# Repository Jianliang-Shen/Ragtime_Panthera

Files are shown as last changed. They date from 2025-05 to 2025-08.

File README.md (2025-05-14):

# Ragtime_Panthera
A set of six axis gripper robotic arm based on DM actuator.

## Acknowledgements

This project was collaboratively developed by **wEch1ng (芝士榴莲肥牛)** and myself.  

The initial concept for the Panthera project was proposed by wEch1ng. During its development, I provided **technical guidance**, **environment setup**, **partial sponsorship**, and was heavily involved in **debugging and hardware verification**, contributing to roughly 'a little bit' of the overall workload.

Both of us built our own arm and worked through some iterations. In fact, the debugging phase was intense—we each sustained minor injuries 🤕 while assembling and tuning the robotic arm, so we sincerely remind everyone: **please prioritize safety** when working with mechanical systems.

The **core structure design**, **initial implementation**, and **main codebase** were led and mostly completed by wEch1ng. My role focused more on **repeated system testing**, **tutorial creation**, and **collaborative validation**. While it was a joint project in many respects, I believe **the primary credit still goes to wEch1ng**, who generously contributed this full-featured robotic arm and gripper system to the open-source community.

If you'd like to show appreciation or offer support, please feel free to contact him directly at: **3575868884@qq.com**

> 🙌 Please direct your thanks, recognition, and any donations to **wEch1ng**, the key driving force behind Panthera.

## Tutorials

Updated Python Tutorial DEMO

Working on Installation Guide (ing)



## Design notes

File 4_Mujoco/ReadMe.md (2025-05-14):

# MuJoCo-Panthera Environment Setup

This repository provides a working setup for MuJoCo-based robotic simulation integrated with Kinova arm kinematics. It includes a set of dependencies optimized for Python 3.10 and visualization/control tools.

## Environment Setup

We recommend setting up a clean conda environment.

```bash
# Step 1: Create and activate the environment
conda create --name MuJoCo-Panthera python=3.10
conda activate MuJoCo-Panthera

# Step 2: Upgrade core tools
python -m pip install --upgrade pip setuptools wheel
```

## Dependency Installation
Install the following required packages (for now):
```bash
# Install Pinocchio from conda-forge
conda install pinocchio -c conda-forge

# Install other Python packages (note: numpy is pinned to <2.0.0 due to compatibility)
pip install mujoco dearpygui scipy numpy<2.0.0 pandas matplotlib scikit-learn PyQt6 pyserial -i https://pypi.tuna.tsinghua.edu.cn/simple
```

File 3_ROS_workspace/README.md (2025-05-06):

## ⚠️ Update Notice

> **Starting from commit**: `Together Fixed Axis-6 bug for now.`  
> This marks the beginning of the **latest stable version** of the code.

Previous versions uploaded to this repository were outdated and may contain bugs related to **Axis 6**, such as unexpected behavior during joint control or motion execution.

This commit introduces a revised and tested implementation that addresses these issues.  
We **strongly recommend** starting from this version to ensure proper functionality and stability.

If you were using an earlier version, please consider backing up your changes and switching to the updated codebase.

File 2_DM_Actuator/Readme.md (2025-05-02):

# Motor Documentation and Software

This project uses the following motors:

- **DM4310**
- **DM4340**
- **DM3510**

## Provided Resources

We have included **user manuals** and **PC-side control software** for the above motors. These resources are sourced from the official Gitee repository and are provided here for convenience.

- Manuals and software were downloaded from: [https://gitee.com/kit-miao](https://gitee.com/kit-miao)

If you require more detailed information, updates, or firmware, please visit the official repository directly.

---

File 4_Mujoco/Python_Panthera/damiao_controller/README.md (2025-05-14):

# 达妙Python库

该库支持MAC,Linux,Windows三个平台

**欢迎加入QQ群：677900232 进行达妙电机技术交流。欢迎进入达妙店铺进行点击选购**[首页-达妙智能控制企业店-淘宝网 (taobao.com)](https://shop290016675.taobao.com/?spm=pc_detail.29232929/evo365560b447259.shop_block.dshopinfo.59f47dd6w4Z4dX)

### 1.引用达妙库

默认文件夹下有两个文件DM_CAN.py为所在的电机库，使用的时候

```python
from DM_CAN import *	
```
在此工程中需要使用
```python
from Python_Panthera.damiao_controller.DM_CAN import *
```

电机库相关依赖是serial , numpy 这几个库，记得安装相关依赖。**具体的requirements在目录下面的requirements.txt，这个版本是我目前测试的版本，比这些版本低理论上应该也没啥问题。**

### 2.定义控制对象

定义电机对象，有几个电机就定义几个。重要的事情：不要把masterid设为0x00

```python
Motor1=Motor(DM_Motor_Type.DM4310,0x01,0x11)
Motor2=Motor(DM_Motor_Type.DM4310,0x02,0x12)
Motor3=Motor(DM_Motor_Type.DM4310,0x03,0x13)
```

第一个参数为电机类型，第二个是SlaveID即电机的CANID（电机的ID）,第三个参数是MasterID是主机ID，建议MasterID设置的都不一样，比SlaveID整体高一个。

例如Motor1的SlaveID是0x01，MasterID是0x11.这样是最好。

**MasterID和SlaveID需要在达妙上位机进行设置！！如果出现问题请先检查MasterID是否不和SlaveID冲突，并且不为0x00**

**MasterID不要设置为0x00**

**MasterID不要设置为0x00**

**MasterID不要设置为0x00**

python使用serial串口，波特率是921600，串口进行选择。demo是windows所以是'COM8'

```python
serial_device = serial.Serial('COM8', 921600, timeout=0.5)
```

初始化电机控制对象。传入参数是定义的串口对象

```python
MotorControl1=MotorControl(serial_device)
```

### 3.电机状态

#### 3.1 添加电机

添加电机是addMotor。

```python
MotorControl1.addMotor(Motor1)
MotorControl1.addMotor(Motor2)
MotorControl1.addMotor(Motor3)
```

#### 3.2使能电机

**建议：如果要修改电机参数。建议使能放在最后**

```python
MotorControl1.enable(Motor1)
MotorControl1.enable(Motor2)
MotorControl1.enable(Motor3)
```

此代码为兼容旧固件，关于旧版本电机固件，使能对应不同模式需要加上使能的模式（即需要使能电机对应的模式，并不能修改电机此时的模式）**注意需要使能电机此时对应的模式，并不能修改电机内部的模式**

```python
MotorControl1.enable_old(Motor1,Control_Type.MIT)
MotorControl1.enable_old(Motor2,Control_Type.POS_VEL)
MotorControl1.enable_old(Motor3,Control_Type.VEL)
```

#### 3.3设置电机零点

将电机在失能状态下摆到需要设置为0点的位置，然后运行下面两行，电机将会将当前位置作为电机0点。

```python
MotorControl1.set_zero_position(Motor3)
MotorControl1.set_zero_position(Motor6)
```

#### 3.4 失能电机

```python
MotorControl1.disable(Motor3)
MotorControl1.disable(Motor6)
```

#### 3.5 电机状态获取

达妙电机默认是需要每发送一帧控制指令才能获得当前电机力矩、位置、速度等信息。如果在没有发送控制指令的过程中想要获得电机此时的状态可以通过以下指令。

```python
MotorControl1.refresh_motor_status(Motor1)
print("Motor1:","POS:",Motor1.getPosition(),"VEL:",Motor1.getVelocity(),"TORQUE:",Motor1.getTorque())
```

通过**refresh_motor_status**这个函数可以获得当前电机的状态，并保存到对应的电机。

### 4.电机控制模式

**推荐在每帧控制完后延迟2ms或者1ms，usb转can默认有缓冲器没有延迟也可使用，但是推荐加上延迟。**

#### 4.1MIT模式

使能电机后可以使用MIT模式控制，推荐用MIT模式控制。

```python
MotorControl1.controlMIT(Motor1, 50, 0.3, 0, 0, 0)
```

#### 4.2位置速度模式

位置速度模式，第一个参数是电机对象，第二个是位置，第三个是转动速度。具体的参数介绍已经写了函数文档，用pycharm等ide就可以看到。

例子如下

```python
q=math.sin(time.time())
MotorControl1.control_Pos_Vel(Motor1,q*10,2)
```

#### 4.3 速度模式

例子如下，第一个是电机对象，第二个是电机速度

```python
q=math.sin(time.time())
MotorControl1.control_Vel(Motor1, q*5)
```

目前达妙的新固件支持切换

#### 4.4力位混合模式

第一个是电机对象，第二个是电机位置，第三个是电机速度范围是0-10000，第四个是电机电流范围为0-10000。具体详细请查看达妙文档

例子如下

```python
MotorControl1.control_pos_force(Motor1, 10, 1000,100)
```

### 5.电机状态读取

电机的各个状态都保存在对应的电机对象中，需要调用可以用如下几个函数。

**请注意！达妙的电机状态是每次发了控制帧或者刷新状态(refresh_motor_status 函数)后才能刷新电机对象的当前各个信息。！！**

**达妙电机是一发一收模式，只有发送指令电机才会返回当前状态，电机才会更新**

```python
vel = Motor1.getVelocity()    #获得电机速度
pos = Motor1.getPosition()    #获得电机位置
tau = Motor1.getTorque()      #获得电机此时输出力矩
```

```maltab
MotorControl1.refresh_motor_status(Motor1)  print("Motor1:","POS:",Motor1.getPosition(),"VEL:",Motor1.getVelocity(),"TORQUE:",Motor1.getTorque())
```

### 6.电机内部参数更改

达妙电机新固件支持使用can进行电机模式修改，以及修改其他参数等操作。要求版本号5013及以上。具体请咨询达妙客服。**请注意所有保存参数、修改参数。请在失能模式下修改！！**

#### 6.1电机控制模式更改

通过下面的函数可以对电机的控制模式进行修改。支持MIT,POS_VEL,VEL,Torque_Pos。四种控制模式在线修改。下面是修改的demo。并且代码会有返回值，如果是True那么说明设置成功了，如果不是也不一定没修改成功hhhh。**请注意这里模式修改只是当前有效，掉电后这个模式还是修改前的**

```python
if MotorControl1.switchControlMode(Motor1,Control_Type.POS_VEL):
    print("switch POS_VEL success")
if MotorControl1.switchControlMode(Motor2,Control_Type.VEL):
    print("switch VEL success")
```

**如果要保持电机控制模式，需要最后保存参数**

#### 6.2保存参数

默认电机修改模式等操作后参数不会保存到flash中，需要使用命令如下进行保存至电机的flash中。这一个例子如下。**请注意这一个代码就把所有修改的都保存到Motor1的flash中，并且请在失能模式下进行修改**，该函数内部有自动失能的代码，防止电机在使能模式下无法保存参数。

```python
MotorControl1.save_motor_param(Motor1)
```

#### 6.3 读取内部寄存器参数

内部寄存器有很多参数都是可以通过can线读取，具体参数列表请看达妙的手册。其中可以读的参数都已经在DM_variable这个枚举类里面了。可以通过read_motor_param进行读取

```python
print("PMAX:",MotorControl1.read_motor_param(Motor1,DM_variable.PMAX))
print("MST_ID:",MotorControl1.read_motor_param(Motor1,DM_variable.MST_ID))
print("VMAX:",MotorControl1.read_motor_param(Motor1,DM_variable.VMAX))
print("TMAX:",MotorControl1.read_motor_param(Motor1,DM_variable.TMAX))
print("Motor2:")
print("PMAX:",MotorControl1.read_motor_param(Motor2,DM_variable.PMAX))
print("MST_ID:",MotorControl1.read_motor_param(Motor2,DM_variable.MST_ID))
print("VMAX:",MotorControl1.read_motor_param(Motor2,DM_variable.VMAX))
print("TMAX:",MotorControl1.read_motor_param(Motor2,DM_variable.TMAX))
```

并且每次读取参数后，当前的参数也会同时存在对应的电机类里面，通过getParam这个函数进行读取。

```python
print("PMAX",Motor1.getParam(DM_variable.PMAX))
```

#### 6.4改写内部寄存器参数

内部寄存器有一部分是支持修改的，一部分是只读的（无法修改）。通过调用change_motor_param这个函数可以进行寄存器内部值修改。并且也如同上面读寄存器的操作一样，他的寄存器的值也会同步到电机对象的内部值，可以通过Motor1.getParam这个函数进行读取。

**请注意这个修改内部寄存器参数，掉电后会恢复为修改前的，并没有保存**

```python
if MotorControl1.change_motor_param(Motor1,DM_variable.KP_APR,54):
   print("write success")
```

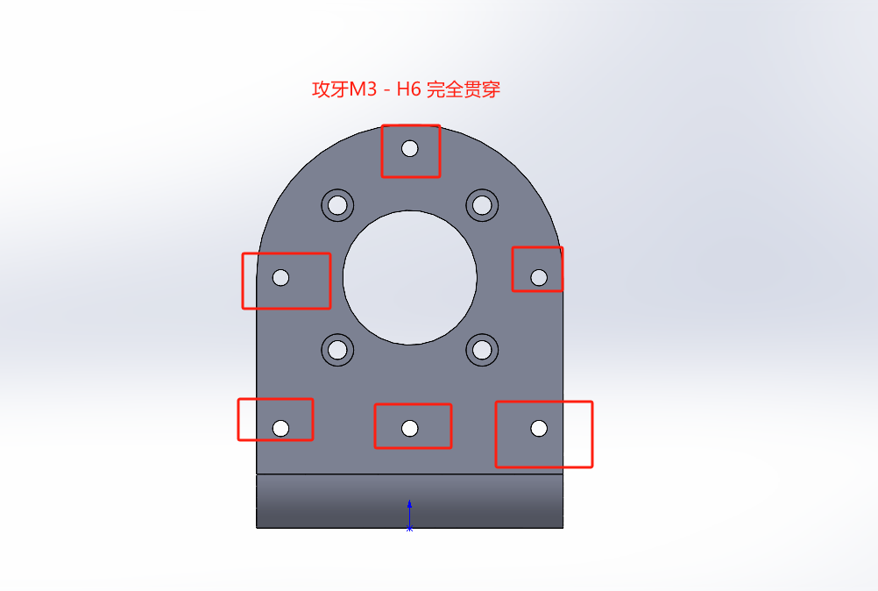
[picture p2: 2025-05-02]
1_3D_Model/2_JLC_metalplate/304_stanless_steel/攻牙图/一二轴.png

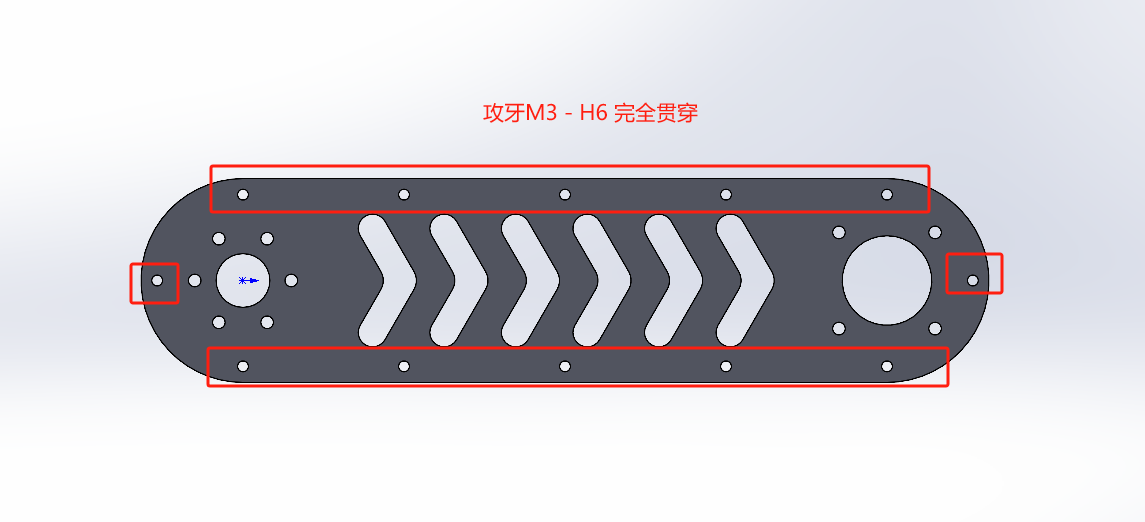
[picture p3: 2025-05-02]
1_3D_Model/2_JLC_metalplate/304_stanless_steel/攻牙图/二三轴.png

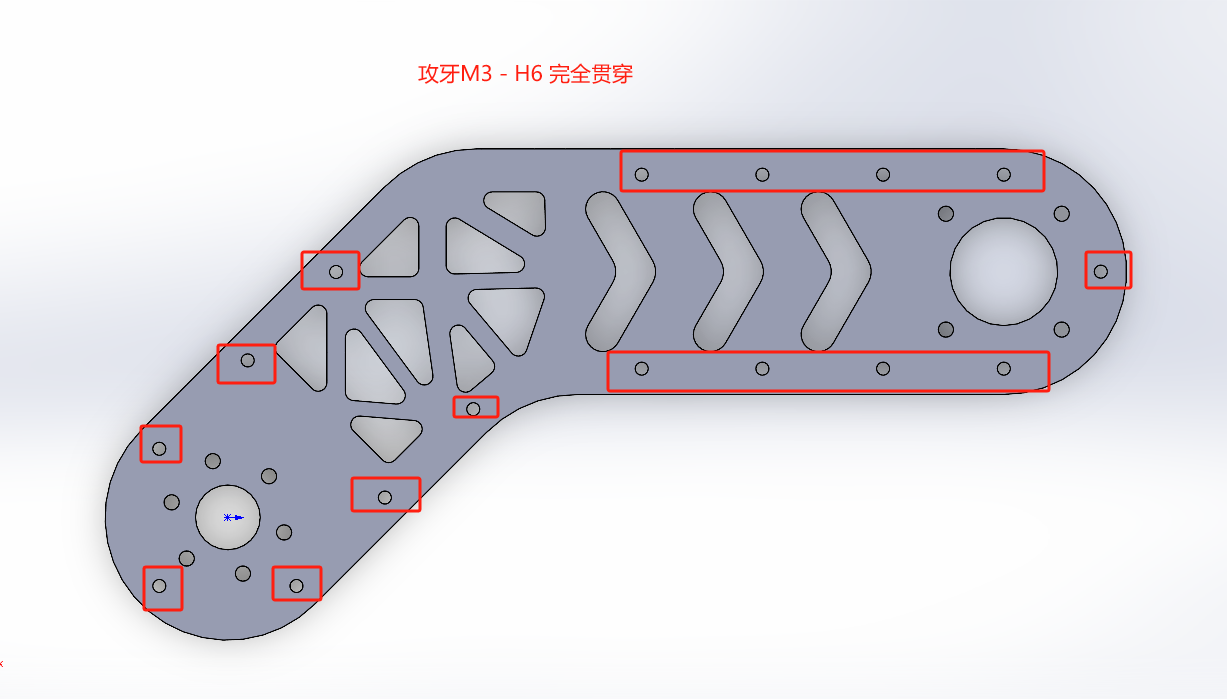
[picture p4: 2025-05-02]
1_3D_Model/2_JLC_metalplate/304_stanless_steel/攻牙图/三四轴.png

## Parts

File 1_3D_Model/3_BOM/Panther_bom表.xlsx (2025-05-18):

序号 | 商品名称 | 数量（件） | 单价 | 总计 | 链接
1 | 若干M3螺丝 | 无 | 无 | 无 | https://detail.tmall.com/item.htm?id=601686286684
2 | 若干M3螺母 | 无 | 无 | 无 | 无
 | 橡胶垫片 M3*6*0.8 (200粒) 白 | 1 | 3.4 | 3.4 | https://detail.tmall.com/item.htm?id=20848580632
3 | 达妙4340电机 | 3 | 799 | 2397 | https://item.taobao.com/item.htm?id=775159686012
4 | 达妙4310新手套装 含USB转CAN 转接板 双端线 | 2 | 669 | 1338 | https://item.taobao.com/item.htm?id=730437945135
5 | 达妙4310电机 | 1 | 599 | 599
6 | 达妙3510电机 | 1 | 199 | 199 | https://item.taobao.com/item.htm?abbucket=4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
7 | XT30（2+2）-F母头升级版 | 14 | 1.85 | 25.9 | https://item.taobao.com/item.htm?id=737472229828
8 | 黑色18AWG | 1 | 14 | 14 | https://item.taobao.com/item.htm?id=654286714565
9 | 红色18AWG | 1 | 14 | 14
10 | 黑色28AWG | 1 | 7 | 7
11 | 红色28AWG | 1 | 7 | 7
12 | 滑块 MGW7C（标准块） | 2 | 18 | 36 | https://item.taobao.com/item.htm?id=848276155434&sku_properties=122276018%3A20213
13 | MGW7导轨100MM（备注做成一根200mm的） | 2 | 10 | 20
14 | 1模凸台20齿 内孔10 | 1 | 4.2 | 4.2 | https://detail.tmall.com/item.htm?id=725141098339
15 | 光学平板300x300x13 | 1 | 275 | 275 | https://item.taobao.com/item.htm?from=cart&id=730306309245&skuId=5230836882690&u_channel=null&umpChannel=null
16 | 嘉立创钣金定制 | 5 | 50 | 250 | 立创下单平台
 | 总价 | 5189.5
 | 3D打印材料
 | 兰博abs+
 | https://detail.tmall.com/item.htm?_u=o2rtso892077&id=645580609321&spm=a1z09.2.0.0.40262e8drWVAiV

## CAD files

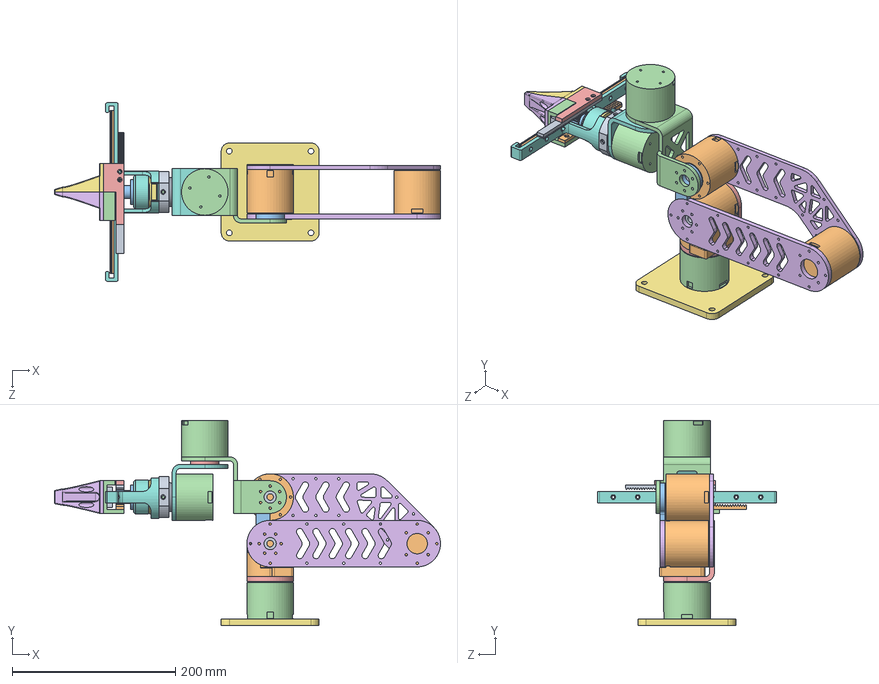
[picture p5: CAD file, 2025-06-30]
1_3D_Model/0_Solidworks2022/无d435/arm/myrobot.SLDASM
472.5 x 251.5 x 218.6 mm
4340电机转子 x 3
4340电机定子 x 3
4310电机转子 x 3
4310电机定子 x 3
一二轴连接件
二三轴连杆
底板
五六轴连接件1
末端法兰
二三轴连杆定位件
四五轴连杆定位件
四五轴连接件
五六轴垫块
三四轴连杆
3510定子
3510转子
MGW9C滑块 x 2
MGW9导轨
转子齿轮连接件
滑块手指连接件
滑块手指连接件2
手指
镜向手指
夹爪外壳
齿条
齿条2
spur gear_gb
外壳内挡块

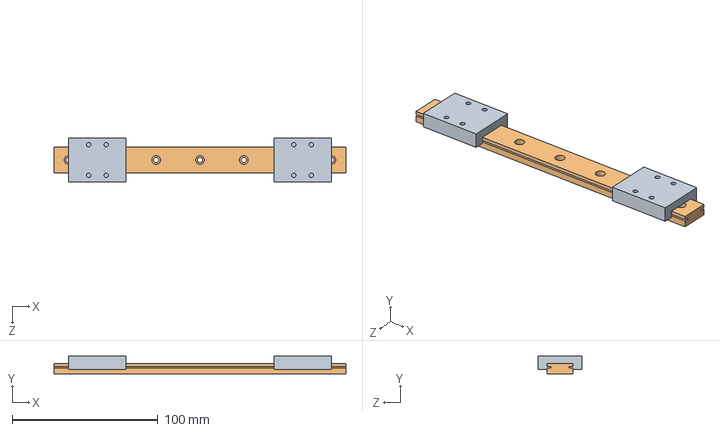
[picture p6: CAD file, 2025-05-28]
1_3D_Model/0_Solidworks2022/无d435/gripper/MGW9导轨滑块模组/MGW9滑轨模组.SLDASM
200.0 x 12.0 x 30.0 mm
MGW9C滑块 x 2
MGW9导轨

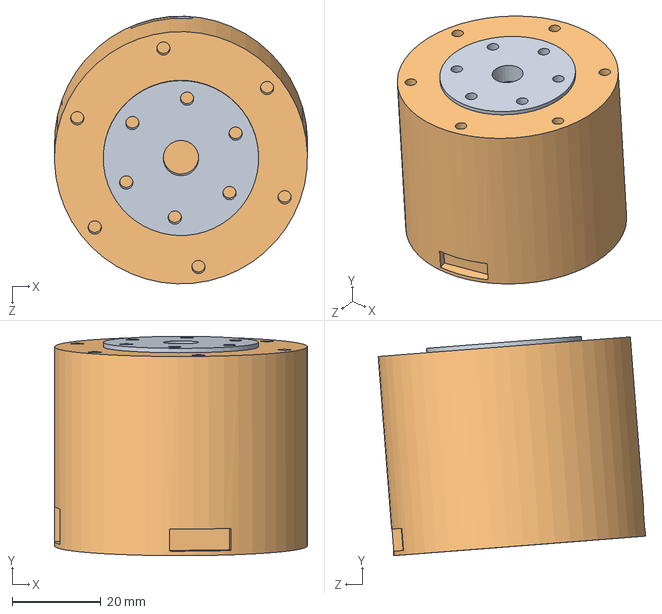
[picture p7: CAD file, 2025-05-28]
1_3D_Model/0_Solidworks2022/有d435/arm/4310电机/4310电机装配体.SLDASM
57.0 x 49.4 x 60.3 mm
4310电机转子
4310电机定子

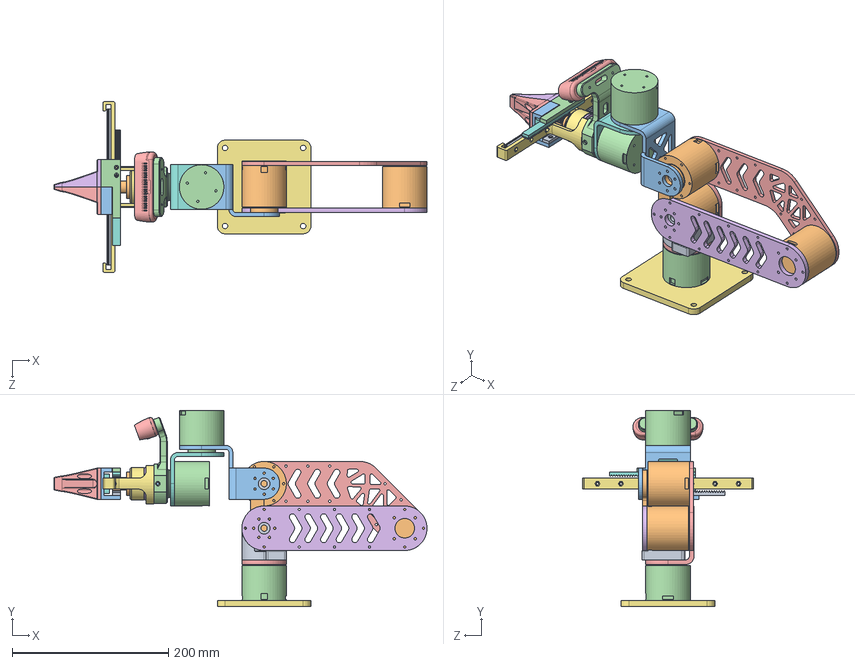
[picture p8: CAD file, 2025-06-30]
1_3D_Model/0_Solidworks2022/有d435/arm/myrobot.SLDASM
477.5 x 251.5 x 218.6 mm
4340电机转子 x 3
4340电机定子 x 3
4310电机转子 x 3
4310电机定子 x 3
一二轴连接件
二三轴连杆
底板
五六轴连接件1
二三轴连杆定位件
四五轴连杆定位件
四五轴连接件
五六轴垫块
三四轴连杆
3510定子
3510转子
MGW9C滑块 x 2
MGW9导轨
转子齿轮连接件
滑块手指连接件
滑块手指连接件2
手指
镜向手指
夹爪外壳
齿条
齿条2
spur gear_gb
外壳内挡块
法兰(带d435)
IntelRealsense_D435_Multibody

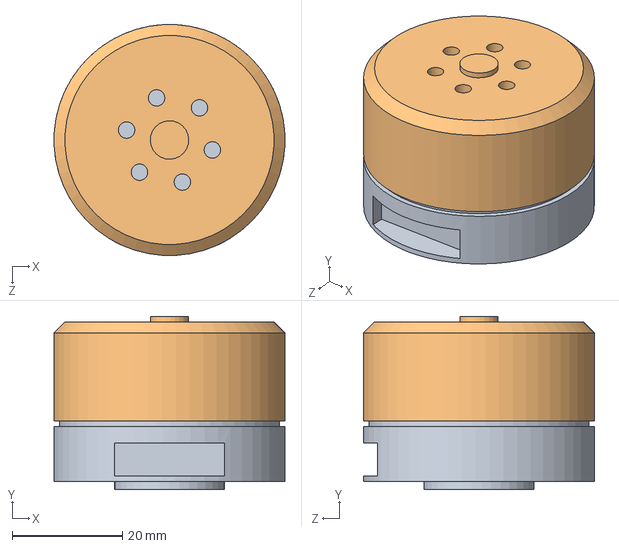
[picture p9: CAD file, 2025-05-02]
1_3D_Model/0_Solidworks2022/无d435/gripper/达妙3510轮毂电机/3510.SLDASM
42.0 x 31.5 x 42.0 mm
3510定子
3510转子

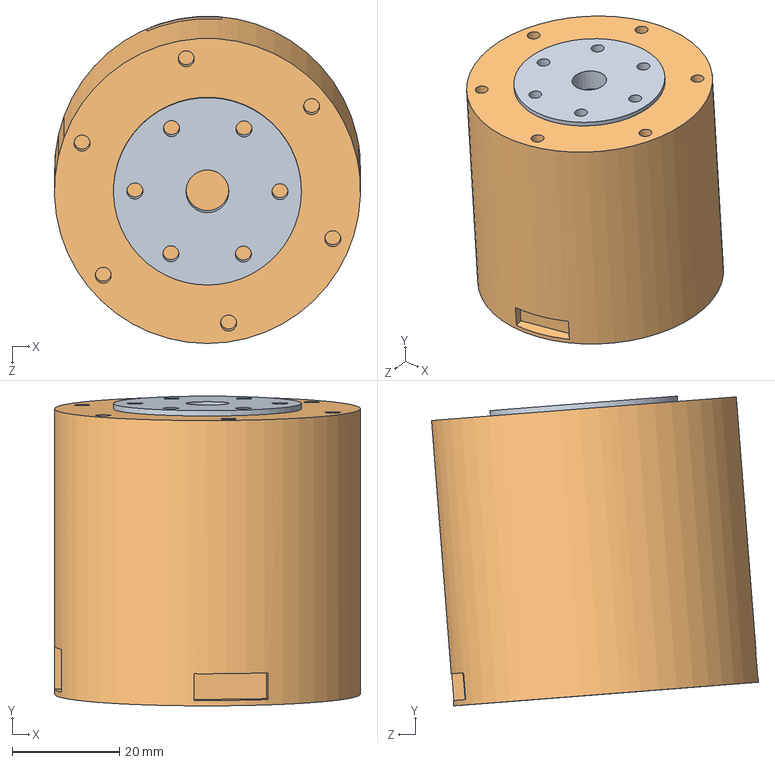
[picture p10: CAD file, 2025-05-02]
1_3D_Model/0_Solidworks2022/有d435/arm/4340电机/4340电机装配体.SLDASM
57.0 x 57.7 x 60.9 mm
4340电机转子
4340电机定子

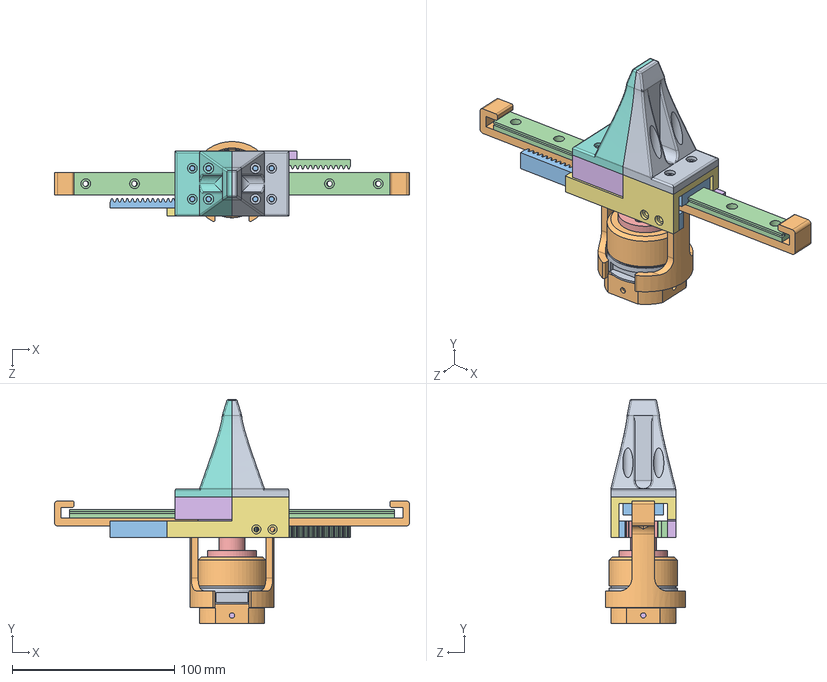
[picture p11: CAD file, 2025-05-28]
1_3D_Model/0_Solidworks2022/无d435/gripper/MyGripper.SLDASM
218.6 x 138.0 x 49.3 mm
3510定子
3510转子
MGW9C滑块 x 2
MGW9导轨
转子齿轮连接件
滑块手指连接件
滑块手指连接件2
手指
镜向手指
夹爪外壳
齿条
齿条2
spur gear_gb
外壳内挡块

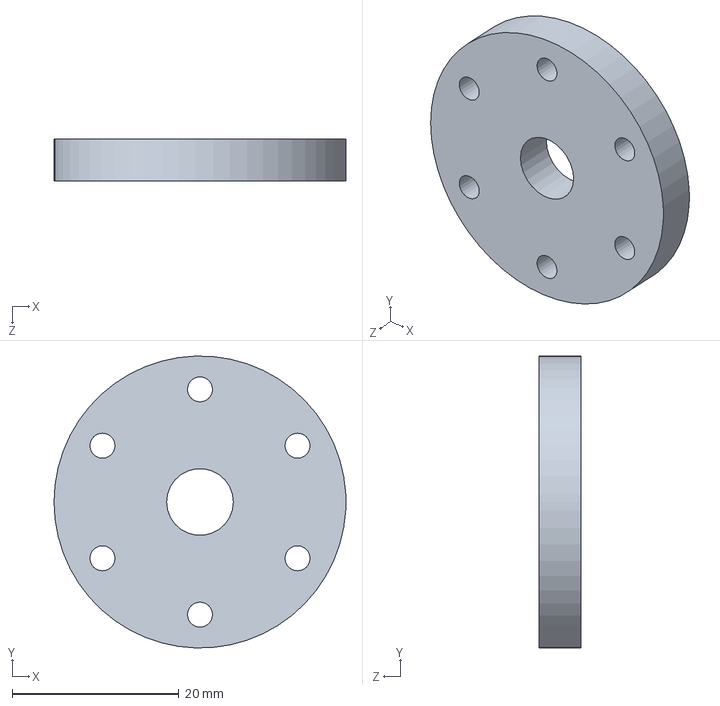
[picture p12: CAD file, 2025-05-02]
1_3D_Model/0_Solidworks2022/无d435/arm/4310电机/4310电机转子.SLDPRT
35.0 x 35.0 x 5.00 mm

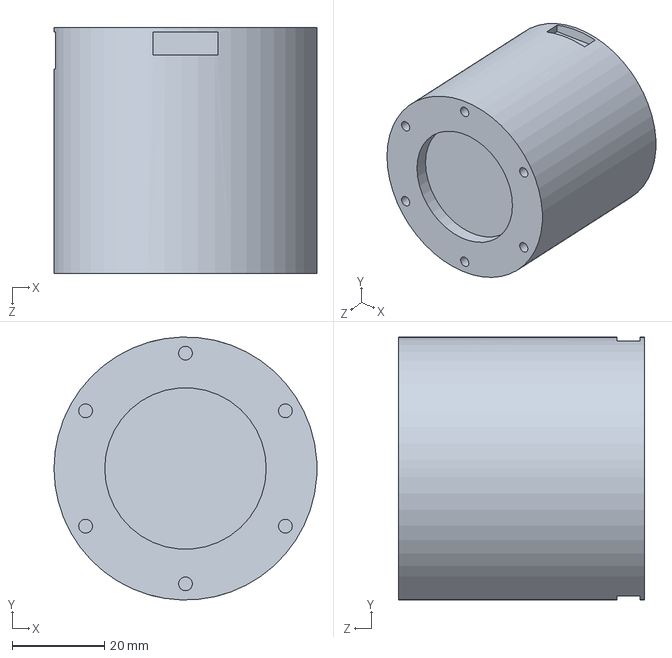
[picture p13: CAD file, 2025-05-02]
1_3D_Model/0_Solidworks2022/无d435/arm/4340电机/4340电机定子.SLDPRT
57.0 x 57.0 x 53.3 mm

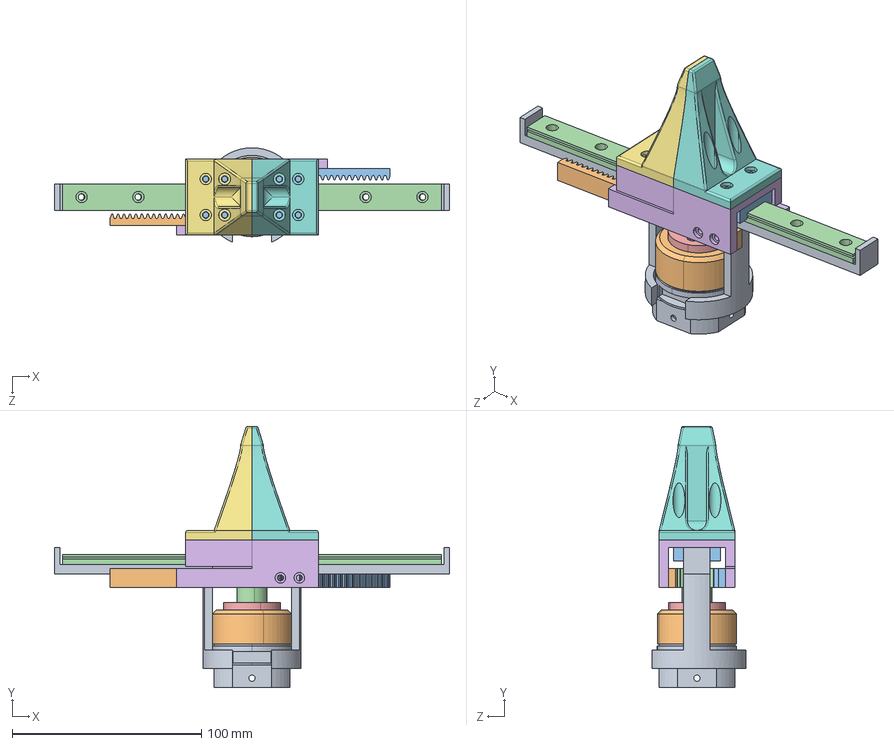
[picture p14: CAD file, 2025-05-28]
1_3D_Model/0_Solidworks2022/无d435/gripper/平行夹爪step/MyGripper.STEP
208.6 x 138.0 x 49.9 mm
3510隅赽
3510蛌赽
MGW9C賑輸 x 2
MGW9絳寢
转子齿轮连接件
滑块手指连接件
滑块手指连接件2
忒硌
镜向手指
ｼﾐﾗｦﾍ篩ﾇ
喘沭
喘沭2
spur gear_gb_GB - Spur gear 1M 20T 20PA 10FW ---S20B16H18L10.0N

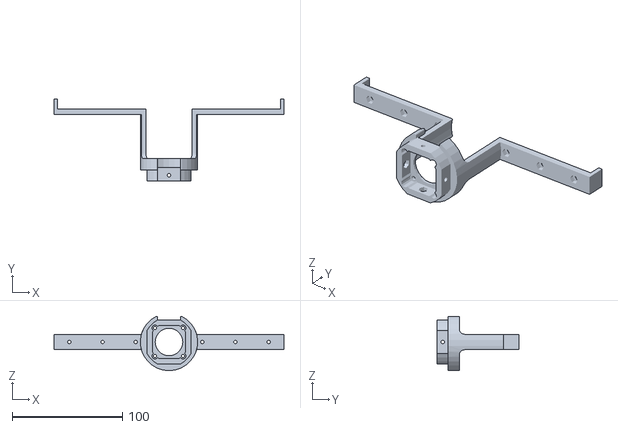
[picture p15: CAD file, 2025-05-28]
1_3D_Model/0_Solidworks2022/无d435/gripper/平行夹爪stl/夹爪外壳.STL
208.6 x 74.0 x 49.3

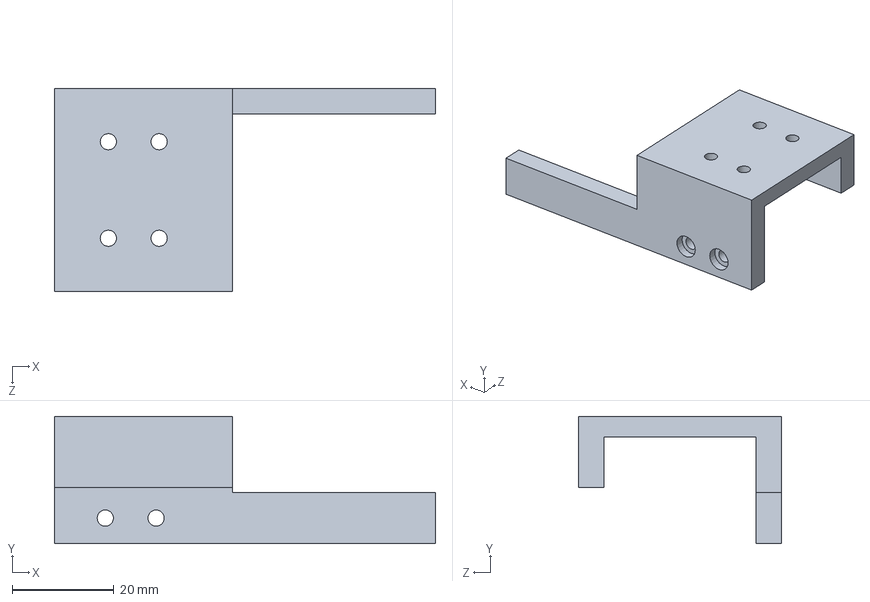
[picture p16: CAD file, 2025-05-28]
1_3D_Model/0_Solidworks2022/无d435/gripper/滑块手指连接件2.SLDPRT
75.0 x 25.0 x 40.0 mm

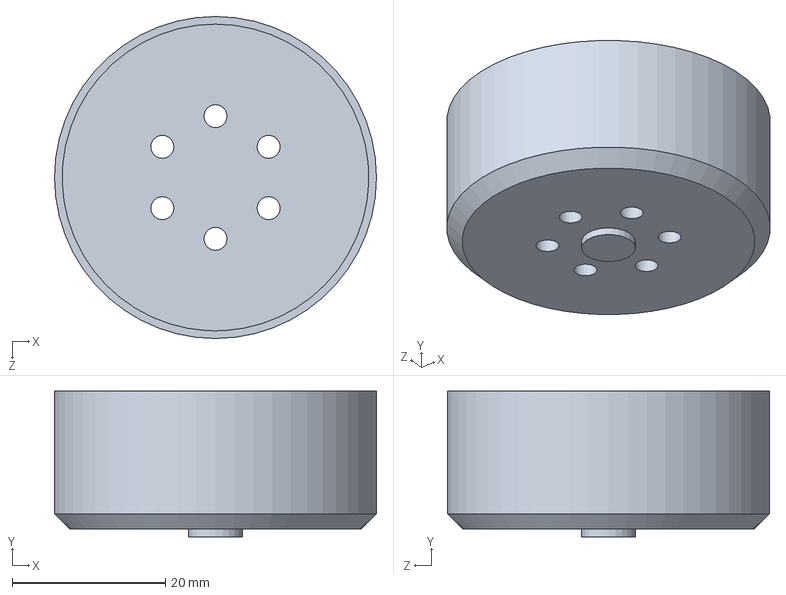
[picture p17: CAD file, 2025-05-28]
1_3D_Model/0_Solidworks2022/无d435/gripper/达妙3510轮毂电机/3510转子.SLDPRT
42.0 x 19.0 x 42.0 mm

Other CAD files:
1_3D_Model/0_Solidworks2022/无d435/arm/4310电机/4310电机装配体.SLDASM
1_3D_Model/0_Solidworks2022/有d435/gripper/MyGripper.SLDASM
1_3D_Model/0_Solidworks2022/无d435/arm/4310电机/4310电机定子.SLDPRT
1_3D_Model/0_Solidworks2022/无d435/arm/4340电机/4340电机转子.SLDPRT
1_3D_Model/0_Solidworks2022/无d435/arm/一二轴连接件.SLDPRT
1_3D_Model/0_Solidworks2022/无d435/arm/三四轴连杆.SLDPRT
1_3D_Model/0_Solidworks2022/无d435/arm/二三轴连杆.SLDPRT
1_3D_Model/0_Solidworks2022/无d435/arm/二三轴连杆定位件.SLDPRT
1_3D_Model/0_Solidworks2022/无d435/arm/五六轴垫块.SLDPRT
1_3D_Model/0_Solidworks2022/无d435/arm/五六轴连接件1.SLDPRT
1_3D_Model/0_Solidworks2022/无d435/arm/从动轴.SLDPRT
1_3D_Model/0_Solidworks2022/无d435/arm/四五轴连接件.SLDPRT
1_3D_Model/0_Solidworks2022/无d435/arm/四五轴连杆定位件.SLDPRT
1_3D_Model/0_Solidworks2022/无d435/arm/圆头末端.SLDPRT
1_3D_Model/0_Solidworks2022/无d435/arm/底板.SLDPRT
1_3D_Model/0_Solidworks2022/无d435/gripper/1模20齿凸台齿轮.SLDPRT
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

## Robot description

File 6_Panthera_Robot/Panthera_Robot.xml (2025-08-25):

<mujoco model="Panthera_Robot">
  <compiler angle="radian"/>

  <visual>
    <global azimuth="140" elevation="-30"/>
    <headlight ambient="0.3 0.3 0.3" diffuse="0.6 0.6 0.6" specular="0 0 0"/>
    <rgba haze="0.15 0.25 0.35 1"/>
  </visual>

  <statistic extent="0.4" center="0 -0.2 0.1"/>

  <asset>
    <texture type="skybox" colorspace="auto" builtin="gradient" rgb1="0.3 0.5 0.7" rgb2="0 0 0" width="512" height="3072"/>
    <texture type="2d" colorspace="auto" name="groundplane" builtin="checker" mark="edge" rgb1="0.2 0.3 0.4" rgb2="0.1 0.2 0.3" markrgb="0.8 0.8 0.8" width="300" height="300"/>
    <texture type="2d" colorspace="linear" name="small_meta_table_diffuse" file="assets/table/small_meta_table_diffuse.png"/>
    <material name="groundplane" texture="groundplane" texuniform="true" texrepeat="5 5" reflectance="0.2"/>
    <mesh name="base_link" content_type="model/stl" file="assets/base_link.STL"/>
    <mesh name="link1" content_type="model/stl" file="assets/link1.STL"/>
    <mesh name="link2" content_type="model/stl" file="assets/link2.STL"/>
    <mesh name="link3" content_type="model/stl" file="assets/link3.STL"/>
    <mesh name="link4" content_type="model/stl" file="assets/link4.STL"/>
    <mesh name="link5" content_type="model/stl" file="assets/link5.STL"/>
    <mesh name="link6" content_type="model/stl" file="assets/link6.STL"/>
    <mesh name="gripper_centor_link" content_type="model/stl" file="assets/gripper_centor_link.STL"/>
    <mesh name="gripper_1_link" content_type="model/stl" file="assets/gripper_1_link.STL"/>
    <mesh name="gripper_2_link" content_type="model/stl" file="assets/gripper_2_link.STL"/>
  </asset>

  <worldbody>
    <geom type="mesh" rgba="0.35 0.35 0.35 1" mesh="base_link"/>
    <geom name="floor" size="0 0 0.05" type="plane" material="groundplane"/>
    <light pos="0 0 1.5" dir="0 0 -1" type="directional"/>
    <body name="link1" pos="0 0 0.105">
      <inertial pos="-0.000140138 -0.0115178 -0.0189176" quat="0.682107 0.225427 -0.213571 0.662043" mass="0.43354" diaginertia="0.000311717 0.000278907 0.000182784"/>
      <joint name="joint1" pos="0 0 0" axis="0 0 1" range="-3.14 3.14" actuatorfrcrange="-3 3" damping="1"/>
      <geom type="mesh" rgba="0.35 0.35 0.35 1" mesh="link1"/>
      <body name="link2" quat="0 0 0.707107 0.707107">
        <inertial pos="0.106425 -3.80251e-12 0.0236078" quat="0 0.70709 0 0.707124" mass="0.618785" diaginertia="0.00238697 0.002245 0.00020352"/>
        <joint name="joint2" pos="0 0 0" axis="0 0 1" range="-3.14 3.14" actuatorfrcrange="-3 3" damping="1"/>
        <geom type="mesh" rgba="0.35 0.35 0.35 1" mesh="link2"/>
        <body name="link3" pos="0.18 0 0" quat="0 0.152738 0.988267 0">
          <inertial pos="0.112948 0.0109257 0.0234931" quat="0.00528254 0.707095 -0.00493839 0.707082" mass="0.578438" diaginertia="0.00237483 0.00216767 0.000267661"/>
          <joint name="joint3" pos="0 0 0" axis="0 0 1" range="-3.14 3.14" actuatorfrcrange="-3 3" damping="1"/>
          <geom type="mesh" rgba="0.35 0.35 0.35 1" mesh="link3"/>
          <body name="link4" pos="0.188809 0 0" quat="0 0.988267 -0.152738 0">
            <inertial pos="0.0513406 -0.0329058 0.0086821" quat="0.43056 0.820934 0.244816 0.284165" mass="0.399529" diaginertia="0.000452305 0.00042805 0.000186662"/>
            <joint name="joint4" pos="0 0 0" axis="0 0 1" range="-3.14 3.14" actuatorfrcrange="-3 3" damping="1"/>
            <geom type="mesh" rgba="0.35 0.35 0.35 1" mesh="link4"/>
            <body name="link5" pos="0.08 0 0" quat="0.499998 -0.5 0.5 0.500002">
              <inertial pos="0 -0.0160776 -0.0180582" quat="0.641375 0.297721 -0.297721 0.641375" mass="0.321862" diaginertia="0.000219661 0.000192353 0.000137367"/>
              <joint name="joint5" pos="0 0 0" axis="0 0 1" range="-3.14 3.14" actuatorfrcrange="-3 3" damping="1"/>
              <geom type="mesh" rgba="0.35 0.35 0.35 1" mesh="link5"/>
              <body name="link6" pos="0 -0.036 0" quat="0.707105 0.707108 0 0">
                <inertial pos="-0.102863 -0.000273062 0.142036" quat="0.687305 -0.137368 -0.13619 0.700138" mass="0.109692" diaginertia="0.000273958 0.000244021 5.2382e-05"/>
                <joint name="joint6" pos="0 0 0" axis="0 0 1" range="-3.14 3.14" actuatorfrcrange="-3 3" damping="1"/>
                <geom type="mesh" rgba="0.35 0.35 0.35 1" mesh="link6"/>
                <geom pos="0 0 0.148" quat="0.707105 0 -0.707108 0" type="mesh" rgba="0.9 0.9 0.9 1" mesh="gripper_centor_link"/>
                <body name="gripper_1_link" pos="0 0 0.148" quat="0.707105 0 -0.707108 0">
                  <inertial pos="-0.0574119 0.00266478 0.00735601" quat="0.879188 0.0380331 -0.0857256 0.467155" mass="0.042689" diaginertia="1.64659e-05 1.48003e-05 1.05472e-05"/>
                  <joint name="gripper_1_joint" pos="0 0 0" axis="0 0 1" type="slide" range="0 0.06" actuatorfrcrange="-0.18 0.18"/>
                  <geom type="mesh" rgba="0.9 0.9 0.9 1" mesh="gripper_1_link"/>
                </body>
                <body name="gripper_2_link" pos="0 0 0.148" quat="0.707105 0 -0.707108 0">
                  <inertial pos="-0.0573873 -0.00294326 -0.00756965" quat="0.447099 0.0886007 -0.0471377 0.888836" mass="0.0427537" diaginertia="1.63558e-05 1.4676e-05 1.06983e-05"/>
                  <joint name="gripper_2_joint" pos="0 0 0" axis="0 0 1" type="slide" range="-0.06 0" actuatorfrcrange="-0.18 0.18"/>
                  <geom type="mesh" rgba="0.9 0.9 0.9 1" mesh="gripper_2_link"/>
                </body>
              </body>
            </body>
          </body>
        </body>
      </body>
    </body>
  </worldbody>
</mujoco>

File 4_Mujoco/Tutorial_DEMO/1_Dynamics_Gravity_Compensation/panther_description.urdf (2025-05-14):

<?xml version="1.0" encoding="utf-8"?>
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
<robot name="panther_description">
  <link name="base_link">
    <inertial>
      <origin xyz="0 -4.4E-05 0.028999" rpy="0 0 0" />
      <mass value="0.3" />
      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
    </inertial>
    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
  </link>
  <link name="link1">
    <inertial>
      <origin xyz="0.00 -0.008491 0.034259" rpy="0 0 0" />
      <mass value="0.65" />
      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
    </inertial>
    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
  </link>
  <joint name="joint1" type="revolute">
    <origin xyz="0 0 0.1005" rpy="0 0 0" />
    <parent link="base_link" />
    <child link="link1" />
    <axis xyz="0 0 1" />
    <limit lower="-3.14" upper="3.14" effort="3" velocity="1" />
  </joint>
  <link name="link2">
    <inertial>
      <origin xyz="0.124560 0.000000 0.017699" rpy="0 0 0" />
      <mass value="0.83" />
      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
    </inertial>
    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
  </link>
  <joint name="joint2" type="revolute">
    <origin xyz="0 0 0" rpy="1.5708 0 3.1416" />
    <parent link="link1" />
    <child link="link2" />
    <axis xyz="0 0 1" />
    <limit lower="-3.14" upper="3.14" effort="3" velocity="1" />
  </joint>
  <link name="link3">
    <inertial>
      <origin xyz="0.15 0.007521 0.017264" rpy="0 0 0" />
      <mass value="0.87" />
      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
    </inertial>
    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
  </link>
  <joint name="joint3" type="revolute">
    <origin xyz="0.18 0 0" rpy="3.1416 0 2.8349" />
    <parent link="link2" />
    <child link="link3" />
    <axis xyz="0 0 1" />
    <limit lower="-3.14" upper="3.14" effort="3" velocity="1" />
  </joint>
  <link name="link4">
    <inertial>
      <origin xyz="0.08 -0.053910 0.004474" rpy="0 0 0" />
      <mass value="0.427" />
      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
    </inertial>
    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
  </link>
  <joint name="joint4" type="revolute">
    <origin xyz="0.18881 0 0" rpy="3.1416 0 -0.30668" />
    <parent link="link3" />
    <child link="link4" />
    <axis xyz="0 0 1" />
    <limit lower="-3.14" upper="3.14" effort="3" velocity="1" />
  </joint>
  <link name="link5">
    <inertial>
      <origin xyz="0.013 0.000000 -0.007913" rpy="0 0 0" />
      <mass value="0.39" />
      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
    </inertial>
    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
  </link>
  <joint name="joint5" type="revolute">
    <origin xyz="0.08 0 0" rpy="-1.5708 1.5708 0" />
    <parent link="link4" />
    <child link="link5" />
    <axis xyz="0 0 1" />
    <limit lower="-3.14" upper="3.14" effort="3" velocity="1" />
  </joint>
  <link name="link6">
    <inertial>
      <origin xyz="0.000018 -0.000159 0.09" rpy="0 0 0" />
      <mass value="0.41" />
      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
    </inertial>
    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
  </link>
  <joint name="joint6" type="revolute">
    <origin xyz="0 -0.036 0" rpy="1.5708 0 0" />
    <parent link="link5" />
    <child link="link6" />
    <axis xyz="0 0 1" />
    <limit lower="-3.14" upper="3.14" effort="3" velocity="1" />
  </joint>
  <link name="gripper_centor_link">
    <inertial>
      <origin xyz="-0.10705 -0.00028388 -3.5921E-09" rpy="0 0 0" />
      <mass value="0.000" />
      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
    </inertial>
    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
  </link>
  <joint name="gripper_centor_joint" type="fixed">
    <origin xyz="0 0 0.148" rpy="0 -1.5708 0" />
    <parent link="link6" />
    <child link="gripper_centor_link" />
    <axis xyz="0 0 0" />
    <limit lower="-3.14" upper="3.14" effort="3" velocity="1" />
  </joint>
  <link name="gripper_1_link">
    <inertial>
      <origin xyz="-0.057427 0.0029609 0.0073892" rpy="0 0 0" />
      <mass value="0.0000" />
      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
    </inertial>
    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
  </link>
  <joint name="gripper_1_joint" type="prismatic">
    <origin xyz="0 0 0.148" rpy="0 -1.5708 0" />
    <parent link="link6" />
    <child link="gripper_1_link" />
    <axis xyz="0 0 -1" />
    <limit lower="0" upper="0.06" effort="0.18" velocity="1" />
  </joint>
  <link name="gripper_2_link">
    <inertial>
      <origin xyz="-0.057387 -0.0029433 -0.0075697" rpy="0 0 0" />
      <mass value="0.000" />
      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
    </inertial>
    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
  </link>
  <joint name="gripper_2_joint" type="prismatic">
    <origin xyz="0 0 0.148" rpy="0 -1.5708 0" />
    <parent link="link6" />
    <child link="gripper_2_link" />
    <axis xyz="0 0 -1" />
    <limit lower="0" upper="0.06" effort="0.18" velocity="1" />
    <mimic joint="gripper_1_joint" multiplier="-1" offset="0" />
  </joint>
</robot>

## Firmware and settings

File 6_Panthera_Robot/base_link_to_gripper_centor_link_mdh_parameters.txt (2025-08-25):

MDH Parameters for base_link_to_gripper_centor_link
==================================================

Joint      theta (rad)  d            a            α (rad)     
------------------------------------------------------------
Joint 1    3.14159265 0.10050000 0.00000000 0.00000000
Joint 2    0.00000000 0.00000000 0.00000000 1.57079633
Joint 3    -2.83491633 0.00000000 0.18000000 -3.14159265
Joint 4    -2.83491266 -0.00000000 0.18880943 3.14159265
Joint 5    -1.57079265 -0.00000016 -0.08000000 1.57079633
Joint 6    0.00000000 0.03600000 -0.00000000 1.57080000

==================================================
Total joints: 6

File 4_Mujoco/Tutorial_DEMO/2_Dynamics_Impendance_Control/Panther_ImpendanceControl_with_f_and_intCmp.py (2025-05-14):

import pinocchio as pin
import serial
import time
import threading

from Python_Panthera.damiao_controller.DM_CAN import *

# ---------- 电机初始化 ----------
# 初始化电机和串口
Motor1 = Motor(DM_Motor_Type.DM4310, 0x01, 0x11)
Motor2 = Motor(DM_Motor_Type.DM4340, 0x02, 0x12)
Motor3 = Motor(DM_Motor_Type.DM4340, 0x03, 0x13)
Motor4 = Motor(DM_Motor_Type.DM4340, 0x04, 0x14)
Motor5 = Motor(DM_Motor_Type.DM4310, 0x05, 0x15)
Motor6 = Motor(DM_Motor_Type.DM4310, 0x06, 0x16)

serial_device1 = serial.Serial('COM13', 921600, timeout=0.5)
dm1 = MotorControl(serial_device1)

# 添加电机
dm1.addMotor(Motor1)
dm1.addMotor(Motor2)
dm1.addMotor(Motor3)
dm1.addMotor(Motor4)
dm1.addMotor(Motor5)
dm1.addMotor(Motor6)

# 设置控制模式
dm1.switchControlMode(Motor1, Control_Type.MIT)
dm1.switchControlMode(Motor2, Control_Type.MIT)
dm1.switchControlMode(Motor3, Control_Type.MIT)
dm1.switchControlMode(Motor4, Control_Type.MIT)
dm1.switchControlMode(Motor5, Control_Type.MIT)
dm1.switchControlMode(Motor6, Control_Type.MIT)

# 使能电机
dm1.enable(Motor1);time.sleep(0.1)
dm1.enable(Motor2);time.sleep(0.1)
dm1.enable(Motor3);time.sleep(0.1)
dm1.enable(Motor4);time.sleep(0.1)
dm1.enable(Motor5);time.sleep(0.1)
dm1.enable(Motor6);time.sleep(0.1)

# ---------- URDF 模型加载 ----------
# 加载URDF模型（替换为你的实际路径）
urdf_path = "../1_Dynamics_Gravity_Compensation/panther_description.urdf"
model = pin.buildModelFromUrdf(urdf_path)
data = model.createData()
model.gravity.linear = np.array([0, 0, -9.81])

# ---------- 阻抗控制参数 ----------
# KLM
K = np.array([50, 65, 110, 130, 110, 300])#刚度系数k
B = np.array([8, 8, 9.5, 9, 7, 8])#阻尼系数b
# MIT
# K = np.array([3.5, 6.5, 8.5, 2.5, 1.5, 0.80])#刚度系数k
# B = np.array([0.85, 1.05, 1.05, 0.35, 0.15, 0.13])#阻尼系数b
# 共享变量
q_des = np.array([0.0, 0.9, 0.9, 0.0, 0.0, 0.0])  # 期望目标位置
v_des = np.zeros(6)
int_error = np.zeros(6)  # 积分误差
Ki = np.array([2.6, 4.0, 4.3, 4.5, 3.5, 1.5])  # 积分增益，可以调
tau_int_max = np.array([0.15, 0.6, 0.52, 0.45, 0.08, 0.2]) * 4  # 静摩擦力矩的 3.5 倍限制
tau_int_min= np.array([0.03, 0.1, 0.52, 0.45, 0.08, 0.2])

# ---------- 阻抗控制线程 ----------
# 共享变量
q = np.zeros(8)  # 关节位置
vel = np.zeros(8)  # 关节速度
f = np.zeros(6)  # 摩擦力补偿
tau = np.zeros(6)  # 最终力矩
data_lock = threading.Lock()

def impedance_control_loop():

    global int_error
    control_rate = 400  # Hz
    control_period = 1.0 / control_rate

    while True:
        start_time = time.time()

        # 刷新电机状态
        dm1.refresh_motor_status(Motor1)
        dm1.refresh_motor_status(Motor2)
        dm1.refresh_motor_status(Motor3)
        dm1.refresh_motor_status(Motor4)
        dm1.refresh_motor_status(Motor5)
        dm1.refresh_motor_status(Motor6)

        # 读取关节位置和速度
        q[0] = Motor1.getPosition()
        q[1] = Motor2.getPosition()
        q[2] = Motor3.getPosition()
        q[3] = Motor4.getPosition()
        q[4] = Motor5.getPosition()
        q[5] = Motor6.getPosition()
        q[6] = 0
        q[7] = 0

        vel[0] = Motor1.getVelocity()
        vel[1] = Motor2.getVelocity()
        vel[2] = Motor3.getVelocity()
        vel[3] = Motor4.getVelocity()
        vel[4] = Motor5.getVelocity()
        vel[5] = Motor6.getVelocity()
        vel[6] = 0
        vel[7] = 0

        # 动力学项计算
        M_full = pin.crba(model, data, q)
        C_full = pin.computeCoriolisMatrix(model, data, q, vel)
        G_full = pin.computeGeneralizedGravity(model, data, q)#M是惯性矩阵，C是科里奥利矩阵，G是重力矩阵

        # 只提取前6个关节部分用于控制
        M = M_full[:6, :6]
        C = C_full[:6, :6]
        G = G_full[:6]

        if vel[0] < -0.006: f[0] = 0.03 * vel[0]
        if vel[0] > 0.006: f[0] = 0.03 * vel[0]

        if vel[1] < -0.006: f[1] = -0.1 + 0.05 * vel[1]
        if vel[1] > 0.006: f[1] = 0.1 + 0.05 * vel[1]
        
        if vel[2] < -0.006: f[2] = -0.15 + 0.05 * vel[2]
        if vel[2] > 0.006: f[2] = 0.15 + 0.05 * vel[2]
        
        if vel[3] < -0.006: f[3] = -0.30 + 0.2 * vel[3]
        if vel[3] > 0.006: f[3] = 0.30 + 0.2 * vel[3]
        
        if vel[4] < -0.01: f[4] = 0.03 - 0.05 * vel[4]
        if vel[4] > 0.01: f[4] = -0.03 - 0.05 * vel[4]

        # 积分计算限幅
        # 更新积分项
        error = q_des - q[:6]
        # 只有当系统没被扰动，误差较小快静止时才启动积分
        # 仅当系统已进入近似稳态时才积累积分误差
        if np.all(np.abs(error) < 0.8) :
        # 积分带泄露
            int_error = 0.99 * int_error + error * control_period
        else :
            int_error *= 0.95

        # 限幅积分量，避免过饱和（以力矩作为限制指标）
        tau_int = Ki * int_error
        tau_int = np.clip(tau_int, -tau_int_max, tau_int_max)
        print("tau_int:", tau_int, "error:", error)

        # 计算阻抗控制输出力矩
        # KLM
        acc_des = K * (q_des - q[:6]) + B * (v_des - vel[:6])
        # tau = M @ acc_des + C @ vel[:6] + G[:6]
        # with f
        # tau = M @ acc_des + C @ vel[:6] + G[:6] + f[:6]
        # with f and limit int compensate
        tau = M @ acc_des + C @ vel[:6] + G[:6] + f[:6] + tau_int

        # tau = G[:6]
        # MIT
        # acc_des = K * (q_des - q[:6]) + B * (v_des - vel[:6])
        # tau = acc_des[:6] + C @ vel[:6] + G[:6] + f[:6]

        # print("tau_cal:", tau)

        # 力矩限幅（基于电机规格）
        tau_limit = np.array([5.5, 26.5, 26.5, 26.5, 5.5, 5.5])
        tau = np.clip(tau, -tau_limit, tau_limit)

        # print(M @ acc_des)
        print("tau_out:", tau)
        # print("q_cur (rad):", q[:6])
        # print("error (rad):", q_des - q[:6])
        # print(M)

        # 输出到电机
        dm1.controlMIT(Motor1, 0.0, 0.0, 0.0, 0.0, tau[0])
        dm1.controlMIT(Motor2, 0.0, 0.0, 0.0, 0.0, tau[1])
        dm1.controlMIT(Motor3, 0.0, 0.0, 0.0, 0.0, tau[2])
        dm1.controlMIT(Motor4, 0.0, 0.0, 0.0, 0.0, tau[3])
        dm1.controlMIT(Motor5, 0.0, 0.0, 0.0, 0.0, tau[4])
        dm1.controlMIT(Motor6, 0.0, 0.0, 0.0, 0.0, tau[5])

        # 控制频率
        elapsed = time.time() - start_time
        time.sleep(max(0, control_period - elapsed - 0.0001))

# ---------- 启动线程 ----------
ic_thread = threading.Thread(target=impedance_control_loop, daemon=True)
ic_thread.start()

# ---------- 主循环保持运行 ----------
try:
    while True:
        time.sleep(1)
except KeyboardInterrupt:
    dm1.disable(Motor1)
    dm1.disable(Motor2)
    dm1.disable(Motor3)
    dm1.disable(Motor4)
    dm1.disable(Motor5)
    dm1.disable(Motor6)
    print("程序终止，所有电机已禁用")

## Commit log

2025-05-02 Initial commit frome local
    [1模20齿凸台齿轮.SLDPRT, 3510.SLDASM, 3510定子.SLDPRT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]
2025-05-06 Together Fixed Axis-6 bug for now.
    [teach.cpp]
2025-05-06 Add ReadMe waning to ROS and mkdir MuJoCo.
    [motion_data.csv]
2025-05-12 Update Python Imp&Gra Tutorial DEMO.
    [panther_description.urdf]
2025-05-14 Panthera Update
    Panthera Update
    [MyGripper.SLDASM, MyGripper.STEP, base_link.STL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]
2025-05-28 update model
    [1模20齿凸台齿轮.SLDPRT, 3510.SLDASM, 3510定子.SLDPRT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]
2025-06-30 update step of 304
    add tapping holes in step of 304
    [myrobot.SLDASM, 三四轴连杆.STEP, 二三轴连杆.STEP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]
2025-08-23 Add mujoco
    [Desk.obj, Panthera_Robot.xml, base_link.STL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]
